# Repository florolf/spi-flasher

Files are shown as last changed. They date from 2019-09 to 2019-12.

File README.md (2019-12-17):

# spi-flasher

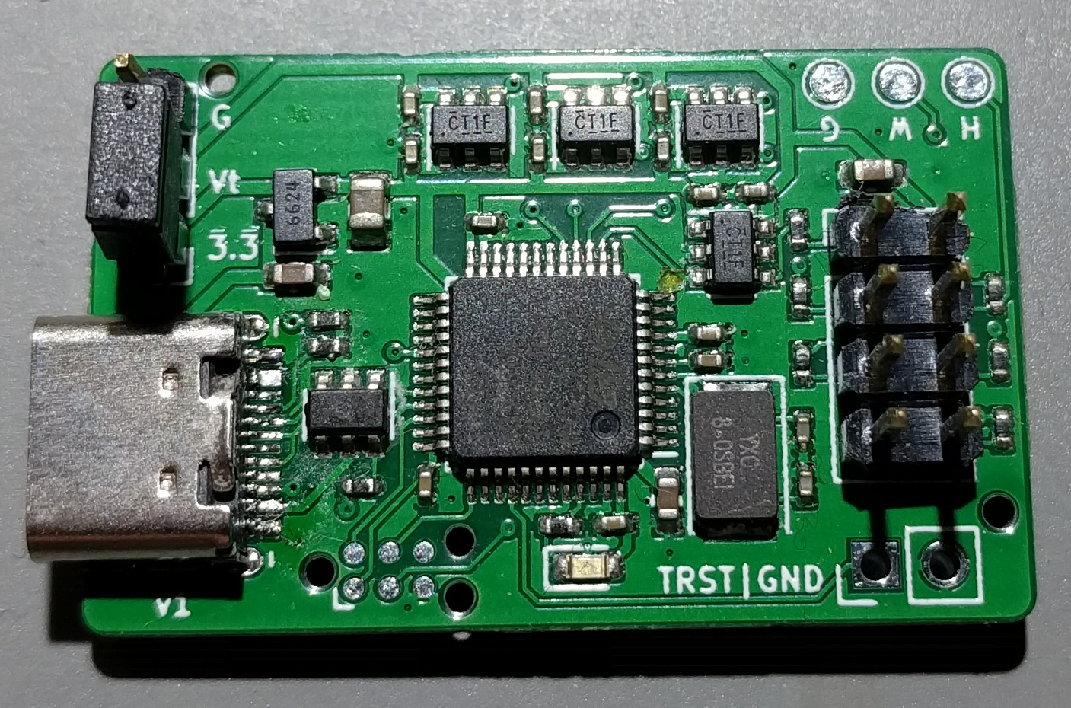
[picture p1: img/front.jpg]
spi-flasher board photo, front
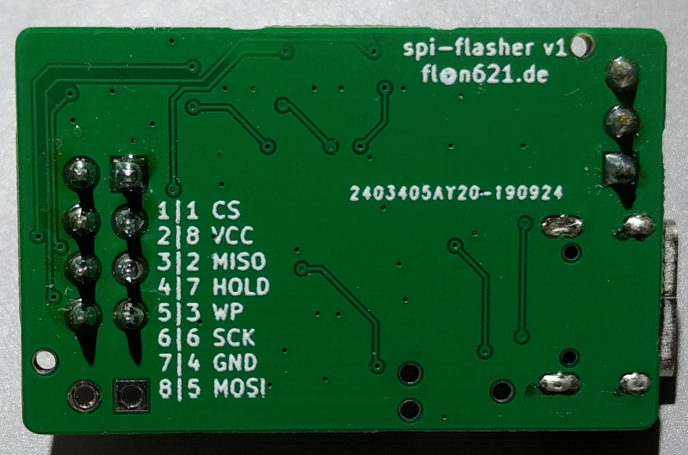
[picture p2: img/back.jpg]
spi-flasher board photo, back


This repository contains an USB-C-to-SPI-flash adapter that is compatible with
[stm32-vserprog](https://github.com/dword1511/stm32-vserprog/) and also has
integrated level-shifters towards the SPI flash. This was created mainly to try
out the JLCPCB assembly service and because there is no convenient way to
program 1.8V flash chips with the "Bluepill + mess of wires" setup I was using
before. The pinout is arranged such that it matches the common flash test
clips.

Furthermore, there is a simple breakout board that flash chips can be directly
soldered onto if space in the target device is too tight to use such a clip
(this is mainly useful when reverse-engineering third-party hardware).

## Hardware

The respective `fab` directories contain fabrication data (and in the case of
the adapter, JLCPCB-style assembly data) for the boards. As JLCPCB cannot
populate connectors at this time, those had to be assembled manually:

 - The dual-row 100mil connector is either a plain dual-row header or a
   shrouded/keyed one.
 - The USB-C connector is a particular family that I sourced from
   [AliExpress](https://aliexpress.com/item/32822609480.html). There doesn't
   seem to be alternative from western distributors that's similarly convenient
   to solder.

The way the target is powered can be selected through the pin header above the
USB port: The target can be self-powered (no jumper), powered from the internal
3.3V rail (jumper between 3.3 and Vt) or powered externally (supply power
between G and Vt).

The TRST/GND connector was meant as an extension that could be used (given a
modified version of `stm32-vserprog`) to keep a target device in reset while
accessing the flash to prevent interference. However, this does not really work
out mechanically, so it was never used.

## Firmware

Build `stm32-vserprog` using `BOARD=stm32-jz01v20` and flash the firmware via
the TagConnect connector.

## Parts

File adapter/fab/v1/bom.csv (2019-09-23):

Comment | Designator | Footprint | LCSC | LCSC | MPN | Manufacturer | DNP
10u | C2 | Capacitor_SMD:C_0805_2012Metric |  | C15850 | CL21A106KAYNNNE | Samsung Electro-Mechanics
20p | C3,C6 | Capacitor_SMD:C_0402_1005Metric |  | C1554 | 0402CG200J500NT | Guangdong Fenghua Advanced Tech
100n | C4,C8,C9,C10,C13,C11,C14,C16,C18,C17,C19,C12,C15 | Capacitor_SMD:C_0402_1005Metric |  | C1525 | CL05B104KO5NNNC | Samsung Electro-Mechanics
1u | C7,C1,C5 | Capacitor_SMD:C_0603_1608Metric |  | C15849 | CL10A105KB8NNNC | Samsung Electro-Mechanics
green | D1 | LED_SMD:LED_0603_1608Metric |  | C72043 | 19-217/GHC-YR1S2/3T | Everlight Elec
USB_C_Receptacle_USB2.0 | J1 | footprints:USB-C_16Pin
Tag-Connect | J2 | Connector:Tag-Connect_TC2030-IDC-NL_2x03_P1.27mm_Vertical |  |  |  |  | DNP
Conn_01x02 | J3 | Connector_PinHeader_2.54mm:PinHeader_1x02_P2.54mm_Vertical
Conn_01x03 | J4 | Connector_PinHeader_2.54mm:PinHeader_1x03_P2.54mm_Vertical
Clip | J5 | Connector_PinHeader_2.54mm:PinHeader_2x04_P2.54mm_Vertical
5k1 | R1,R2 | Resistor_SMD:R_0402_1005Metric |  | C25905 | 0402WGF5101TCE | Uniroyal Elec
220R | R3 | Resistor_SMD:R_0402_1005Metric |  | C25091 | 0402WGF2200TCE | Uniroyal Elec
1k5 | R6 | Resistor_SMD:R_0402_1005Metric |  | C25867 | 0402WGF1501TCE | Uniroyal Elec
1k | R7,R8 | Resistor_SMD:R_0402_1005Metric |  | C11702 | 0402WGF1001TCE | Uniroyal Elec
33R | R9,R10,R4,R5 | Resistor_SMD:R_0402_1005Metric |  | C25105 | 0402WGF330JTCE | Uniroyal Elec
TestPoint | TP3,TP2,TP1 | TestPoint:TestPoint_Pad_D1.5mm |  |  |  |  | DNP
XC6206 | U1 | Package_TO_SOT_SMD:SOT-23 |  | C5446 | XC6206P332MR | Torex Semicon
SRV05-4-P-T7 | U2 | Package_TO_SOT_SMD:SOT-23-6 |  | C85364 | SRV05-4-P-T7 | ProTek Devices
STM32F103C8T6 | U4 | Package_QFP:LQFP-48_7x7mm_P0.5mm |  | C8734 | STM32F103C8T6 | STMicroelectronics
SN74LVC1T45DBV | U5,U7,U8,U6 | Package_TO_SOT_SMD:SOT-23-6 |  | C7843 | SN74LVC1T45DBVR | Texas Instruments
8MHz | Y1 | Crystal:Crystal_SMD_5032-2Pin_5.0x3.2mm |  | C115962 | X50328MSB2GI | Yangxing Tech

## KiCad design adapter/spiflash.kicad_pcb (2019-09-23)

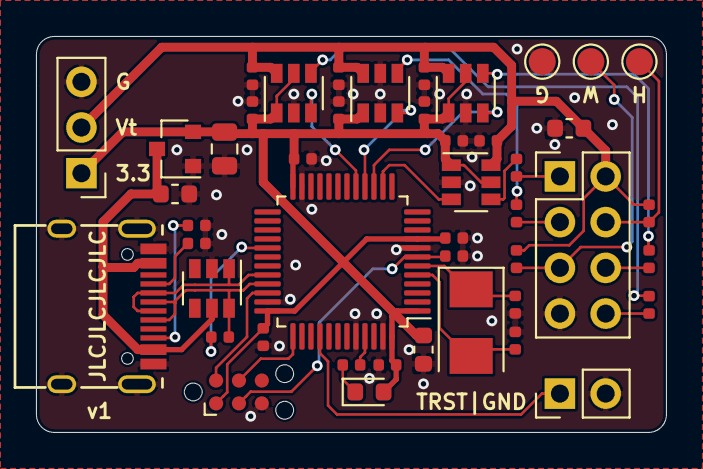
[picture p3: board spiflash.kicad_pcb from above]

Board: 2 copper layers, 35.0 x 22.0 mm, 46 parts (0 on the bottom side), 31 nets.

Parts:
C1, C5, C7: 1u; C_0603_1608Metric
C2: 10u; C_0805_2012Metric
C3, C6: 20p; C_0402_1005Metric
C4, C8, C9, C10, C11, C12, C13, C14, C15, C16, C17, C18, C19: 100n; C_0402_1005Metric
D1: green; LED_0603_1608Metric
J1: USB_C_Receptacle_USB2.0; USB-C_16Pin
J2: Tag-Connect; Tag-Connect_TC2030-IDC-NL_2x03_P1.27mm_Vertical
J3: Conn_01x02; PinHeader_1x02_P2.54mm_Vertical
J4: Conn_01x03; PinHeader_1x03_P2.54mm_Vertical
J5: Clip; PinHeader_2x04_P2.54mm_Vertical
R1, R2: 5k1; R_0402_1005Metric
R3: 220R; R_0402_1005Metric
R4, R5, R9, R10: 33R; R_0402_1005Metric
R6: 1k5; R_0402_1005Metric
R7, R8: 1k; R_0402_1005Metric
TP1, TP2, TP3: TestPoint; TestPoint_Pad_D1.5mm
U1: XC6206; SOT-23
U2: SRV05-4-P-T7; SOT-23-6
U4: STM32F103C8T6; LQFP-48_7x7mm_P0.5mm
U5, U6, U7, U8: SN74LVC1T45DBV; SOT-23-6
Y1: 8MHz; Crystal_SMD_5032-2Pin_5.0x3.2mm

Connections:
+3V3: C2.1, C7.1, C8.1, C9.1, C10.1, C11.1, C12.1, C13.1, C16.1, C17.1, D1.2, J2.1, J4.1, U1.2, U4.1, U4.9, U4.24, U4.36, U4.48, U5.1, U5.5, U6.1, U6.5, U7.1, U7.5, U8.1
/HOLD: J5.4, R7.2, TP2.1
/MISO: R5.1, U8.4
/MISO_MCU: U4.16, U8.3
/MOSI: R10.1, U6.4
/MOSI_MCU: U4.17, U6.3
/NRST: C4.1, J2.3, U4.7
/NSS: R4.1, U5.4
/NSS_MCU: U4.14, U5.3
/SCK: R9.1, U7.4
/SCK_MCU: U4.15, U7.3
/SWCLK: J2.4, U4.37
/SWDIO: J2.2, U4.34
/TRST: J3.1, U4.40
/USB_DM: J1.A7, J1.B7, U2.1, U4.32
/USB_DP: J1.A6, J1.B6, R6.2, U2.6, U4.33
/V_TARGET: C5.1, C14.1, C15.1, C18.1, C19.1, J4.2, J5.2, R7.1, R8.1, U5.6, U6.6, U7.6, U8.6
/WP: J5.5, R8.2, TP3.1
GND: C1.2, C2.2, C3.2, C4.2, C5.2, C6.2, C7.2, C8.2, C9.2, C10.2, C11.2, C12.2, C13.2, C14.2, C15.2, C16.2, C17.2, C18.2, C19.2, J1.A1, J1.B1, J1.S1, J2.5, J3.2, J4.3, J5.7, R1.1, R2.1, TP1.1, U1.1, U2.2, U4.8, U4.23, U4.35, U4.44, U4.47, U5.2, U6.2, U7.2, U8.2, U8.5
unnamed: C3.1, U4.5, Y1.2
unnamed: C6.1, U4.6, Y1.1
unnamed: D1.1, R3.2
unnamed: J1.A5, R1.2
unnamed: J1.B5, R2.2
unnamed: J5.1, R4.2
unnamed: J5.3, R5.2
unnamed: J5.6, R9.2
unnamed: J5.8, R10.2
unnamed: R3.1, U4.45
unnamed: R6.1, U4.29
VBUS: C1.1, J1.A4, J1.B4, U1.3, U2.5

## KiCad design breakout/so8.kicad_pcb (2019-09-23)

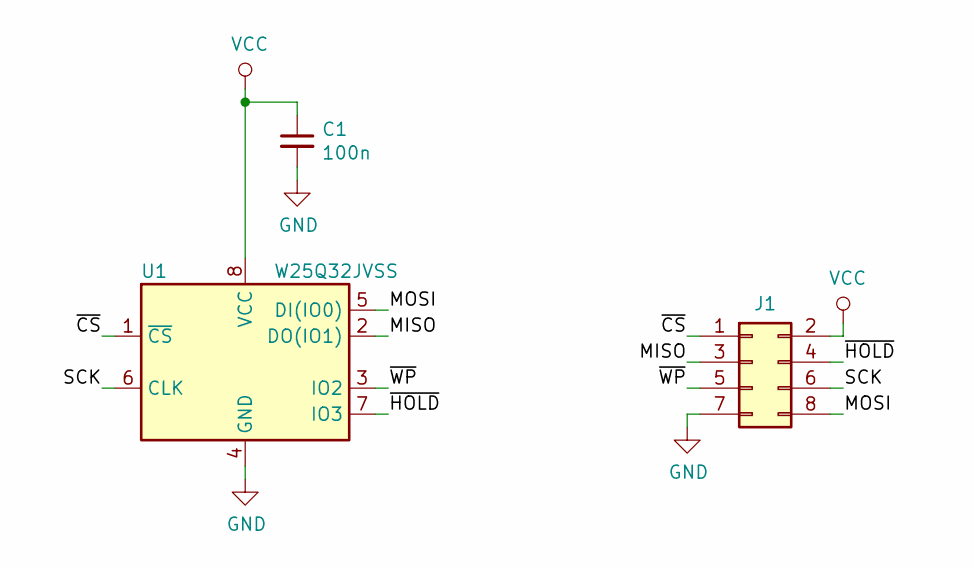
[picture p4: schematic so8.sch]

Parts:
C1: 100n; C_0402_1005Metric
J1: Conn_02x04_Odd_Even; PinSocket_2x04_P1.00mm_Vertical_SMD
U1: W25Q32JVSS; SOIC-8_5.23x5.23mm_P1.27mm

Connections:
/MISO: J1.3, U1.2 (DO(IO1))
/MOSI: J1.8, U1.5 (DI(IO0))
/SCK: J1.6, U1.6 (CLK)
/~CS: J1.1, U1.1 (~CS)
/~HOLD: J1.4, U1.7 (IO3)
/~WP: J1.5, U1.3 (IO2)
GND: C1.2, J1.7, U1.4 (GND)
VCC: C1.1, J1.2, U1.8 (VCC)

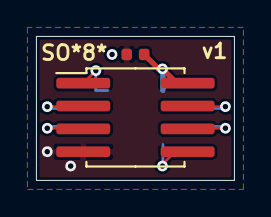
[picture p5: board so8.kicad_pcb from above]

Board: 2 copper layers, 11.0 x 8.0 mm, 3 parts (1 on the bottom side), 8 nets.

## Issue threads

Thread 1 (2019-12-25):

支持哪些种类的闪存芯片呀？

Droid-MAX, 2019-12-25:

florolf, 2019-12-25:
> What kinds of flash memory chips do you support?

This is just a hardware frontend for [flashrom](https://flashrom.org/Flashrom), see their [list](https://flashrom.org/Supported_hardware#Supported_flash_chips) of supported chips.

Electrically, this board supports SPI with 1.8V-5V levels.

Closed 2019-12-27.

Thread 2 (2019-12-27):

breakout转接板有个小问题

Droid-MAX, 2019-12-27:
原理图上没有在VCC/GND引脚上标注PWR_FLAG，导致DCR出现警告！

Closed 2019-12-27.

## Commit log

2019-09-22 move stuff
    [spiflash.kicad_pcb, spiflash.sch]
2019-09-23 adapter: make ERC happy
    [spiflash.sch]
2019-09-23 remap TRST
    [spiflash.kicad_pcb, spiflash.sch]
2019-09-23 add so8 breakout
    [so8.kicad_pcb, so8.sch]
2019-09-23 so8: add fab files
    [so8-B_Cu.gbr, so8-B_Mask.gbr, so8-B_Paste.gbr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]
2019-09-23 adapter: add Vtarget decoupling
    [spiflash.kicad_pcb, spiflash.sch]
2019-09-23 adapter: generate fab data
    [bom.csv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]
2019-09-23 adapter: define crystal loading caps, reexport fab
    [bom.csv, spiflash.kicad_pcb, spiflash.sch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]
2019-09-23 adapter: update CPL to JLC conventions
    [cpl.csv]
2019-09-23 adapter: fix CPL rotations
    [cpl.csv]
2019-12-27 breakout: add PWR_FLAGs
    Add PWR_FLAGs to the supply lines to silence ERC warnings.
    Fixes #2.
    [so8.sch]
